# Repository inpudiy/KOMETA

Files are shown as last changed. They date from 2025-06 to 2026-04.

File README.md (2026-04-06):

# KOMETA

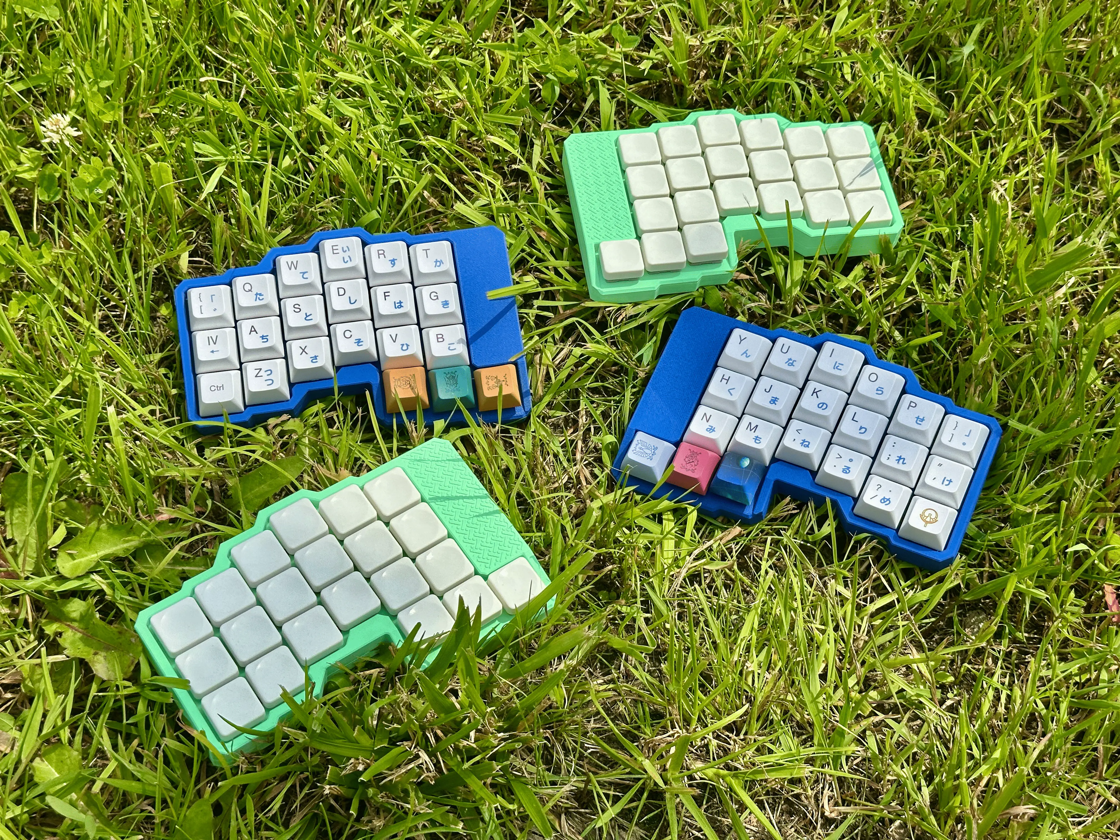
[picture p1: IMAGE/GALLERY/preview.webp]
All


KOMETA is a split keyboard built around Choc switches, designed for wireless operation with Pro Micro–sized microcontrollers. Its key feature is a mid-mount, hot-swappablecontroller design. To enable this, the PCB includes a USB-C port cutout, ensuring compatibility with popular wireless boards like: nice!nano or SuperMini

[Build Guide](BUILD.md) - [ZMK Firmware](https://github.com/inpudiy/zmk-KOMETA)

## Features

- Pro Micro-format microcontroller, compatible with mid-mount hot-swap installation
- Optimized for wireless: hardware power switch, reset button, battery solder pads, no LEDs, and ZMK firmware
- Choc V1/V2 switches with MX spacing (19 × 19 mm)
- 42-key layout with column stagger, inspired by the Jian keyboard
- 3D-printed case

## PCB Image

Bottom
Top

## Case

The repository includes two case variants: the original with angular walls, and a rounded community fork by @max_shu.

## BOM (Bill of Materials)

| Component | Qty |
| --- | --- |
| Pro Micro board: Super Mini nRF52840 / nice!nano | 2 |
| MSK12C02 Slide Switch | 2 |
| 301230 battery | 2 |
| TS342A2P | 2 |
| Silicone bumpers (6x2 mm) | 8 |
| Machine Pin Header Female | 48  |
| 50mm Industrial H62 brass wire 0.5mm thickness | 1 |
| PG1350 hot-swap socket | 42  |
| Diode 1N4148WS (SOD-323) | 42  |
| CHOC V1/2 switches | 42  |
| M2 Hexagon Nut | 12  |
| M2 Thin Flat Head Screw 9mm | 12  |

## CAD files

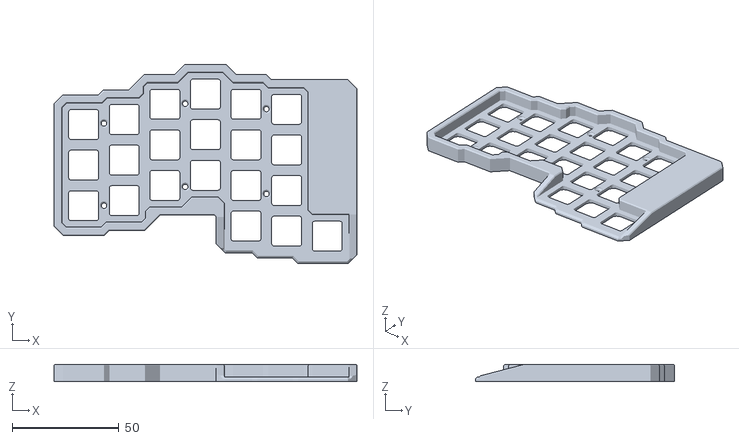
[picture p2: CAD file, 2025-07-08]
CASE/STL/RightPlateNoPattern.stl
141.8 x 93.2 x 8.05

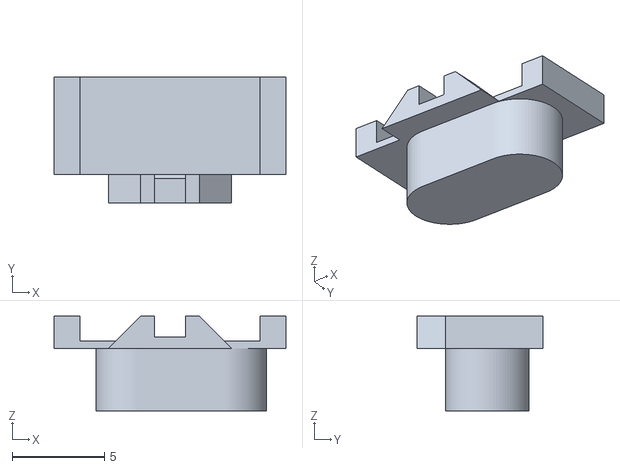
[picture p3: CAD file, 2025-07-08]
CASE/STL/LeftSlider.stl
12.6 x 6.83 x 5.15

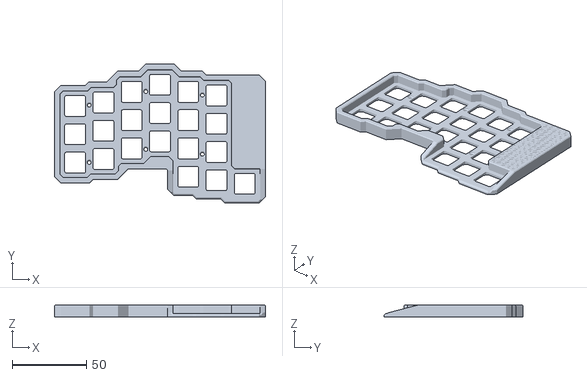
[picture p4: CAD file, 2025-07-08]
CASE/STL/LeftPlate.stl
141.8 x 93.2 x 8.05

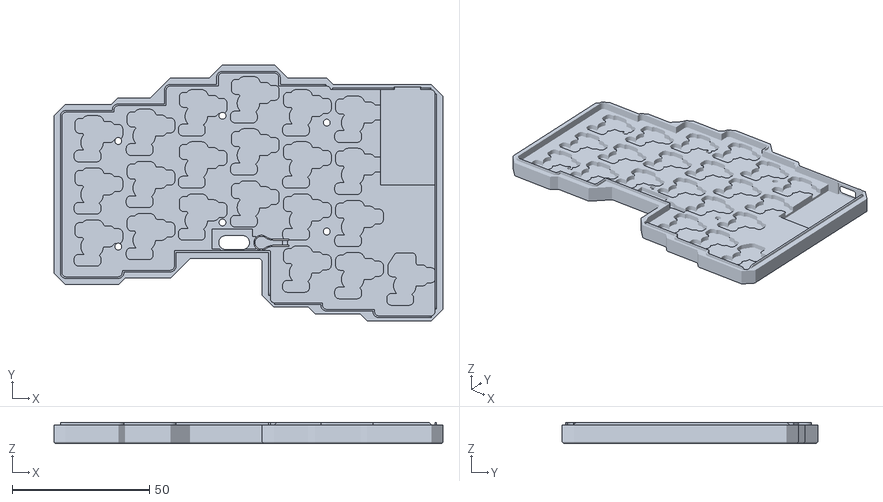
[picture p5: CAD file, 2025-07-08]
CASE/STL/LeftBottom.stl
141.8 x 93.2 x 7.70

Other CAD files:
CASE/STL/RightPlate.stl
CASE/STL/RightSlider.stl
CASE/STL/LeftPlateNoPattern.stl
CASE/STL/RightBottom.stl

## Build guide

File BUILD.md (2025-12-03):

## 1. Tool preparation

For soldering the KOMETA you will need: a soldering iron, solder, flux, side cutters, and tweezers.

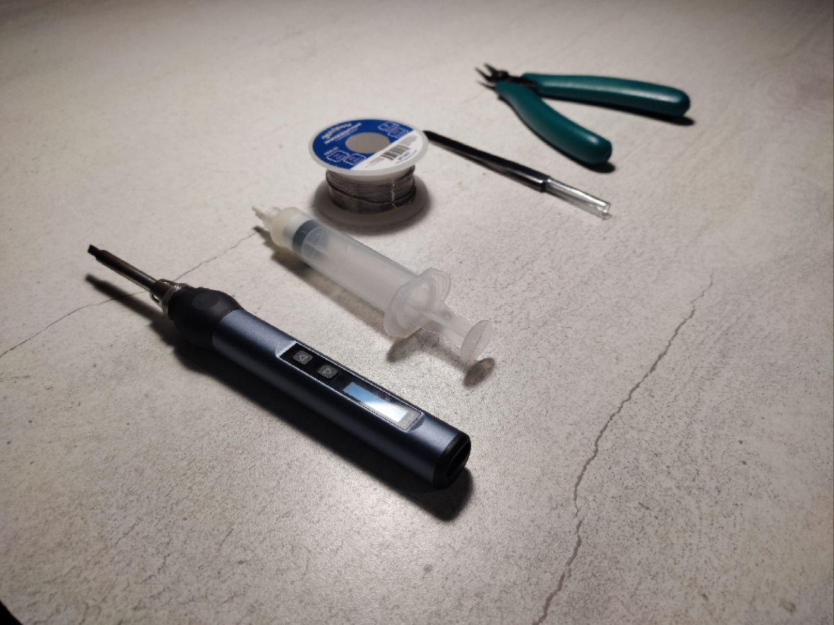
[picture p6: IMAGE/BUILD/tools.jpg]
tools


## 2. Component preparation

For soldering you will need: 2 PCBs, 42 PG1350 hot-swap sockets, 42 1N4148WS diodes, 2 TS342A2P and MSK12C02 switches, any Pro Micro–compatible development board based on the nRF52840 (for example, nice!nano or Super Mini nRF52840), as well as a 301230-sized lithium battery.

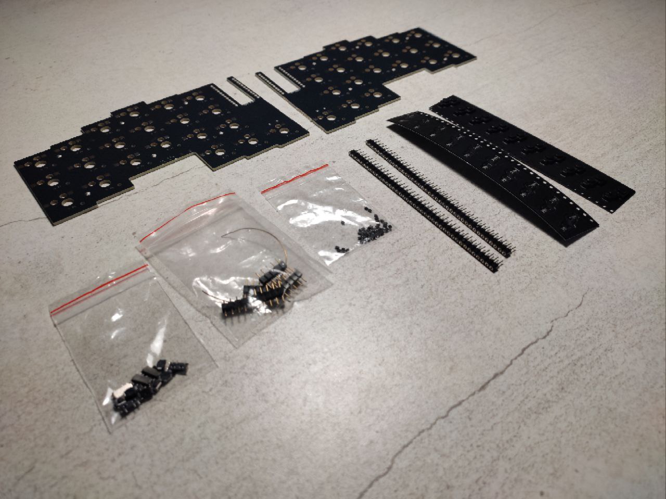
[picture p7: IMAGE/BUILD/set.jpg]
set


## 3. Soldering the diodes

The first step is to tin one pad of each diode footprint with a small amount of solder.

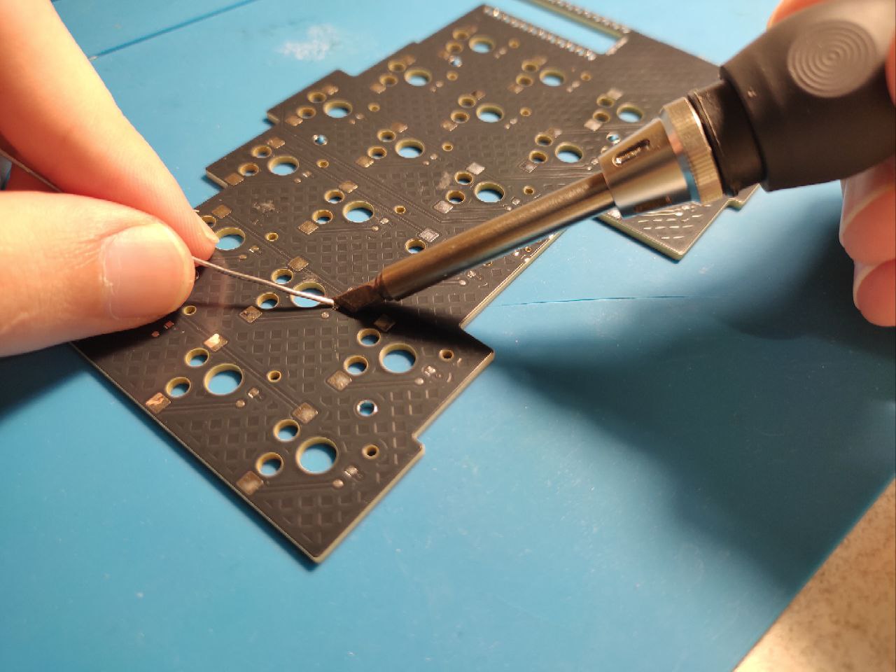
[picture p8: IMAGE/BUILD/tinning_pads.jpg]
tinnig


Next, align the stripe on the diode with the stripe on the PCB, which is located closer to the square pad.

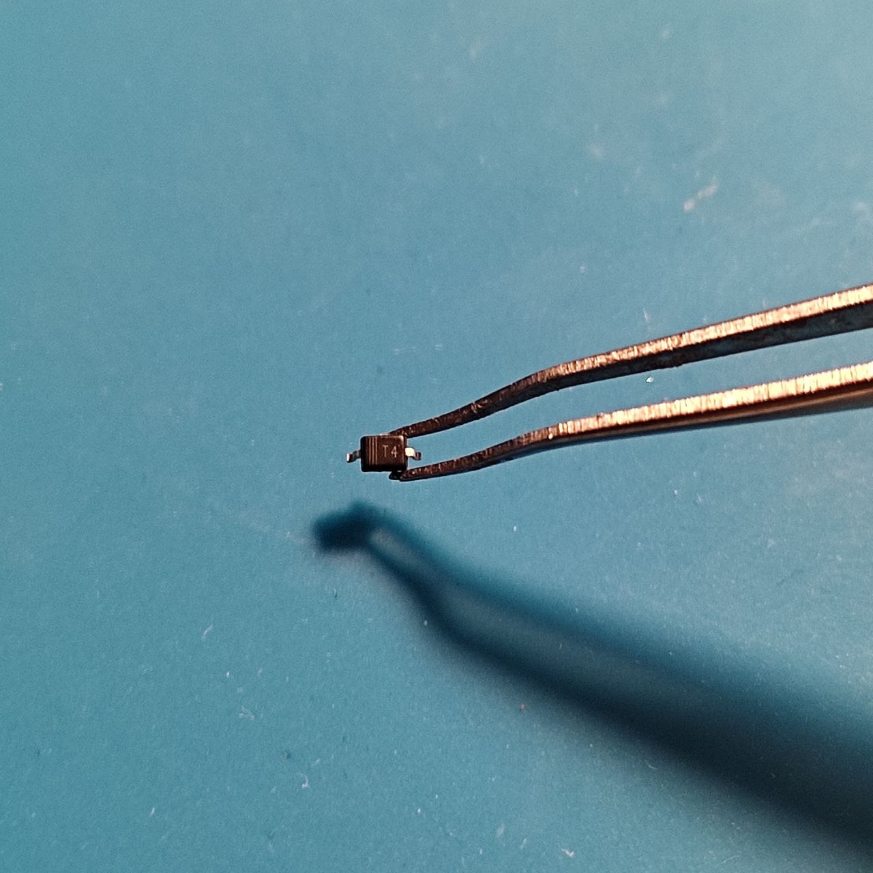
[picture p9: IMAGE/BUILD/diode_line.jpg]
diode_line

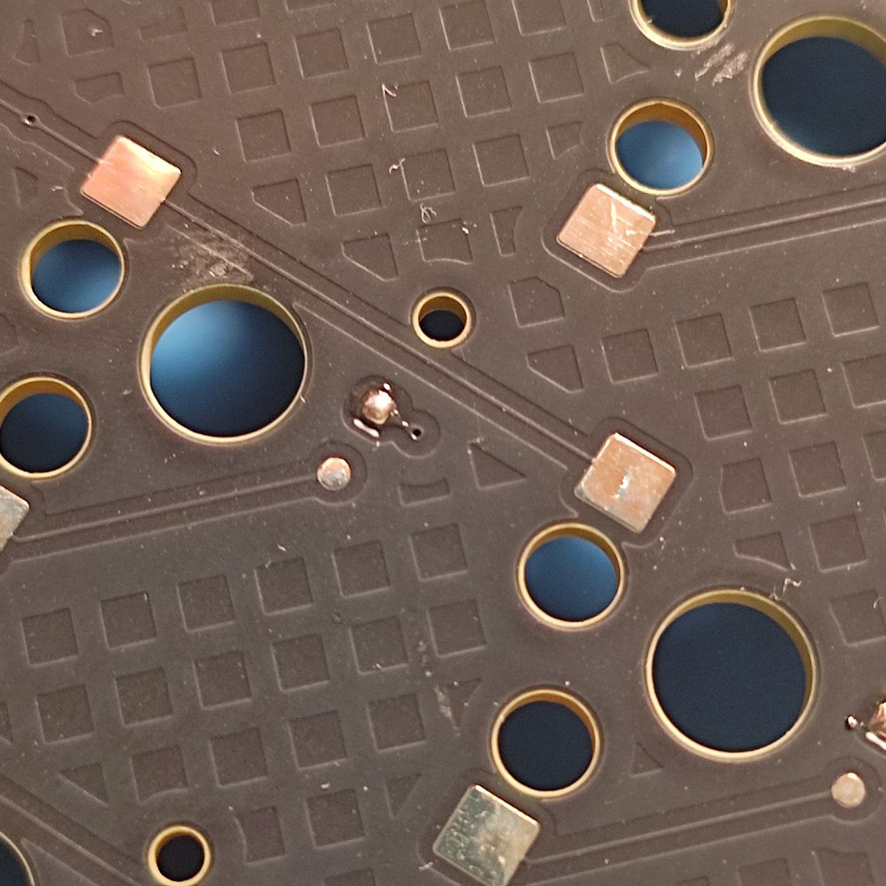
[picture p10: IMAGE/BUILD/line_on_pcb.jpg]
pcb_line


After that, use the soldering iron to reheat the tinned pad and place the diode in position.

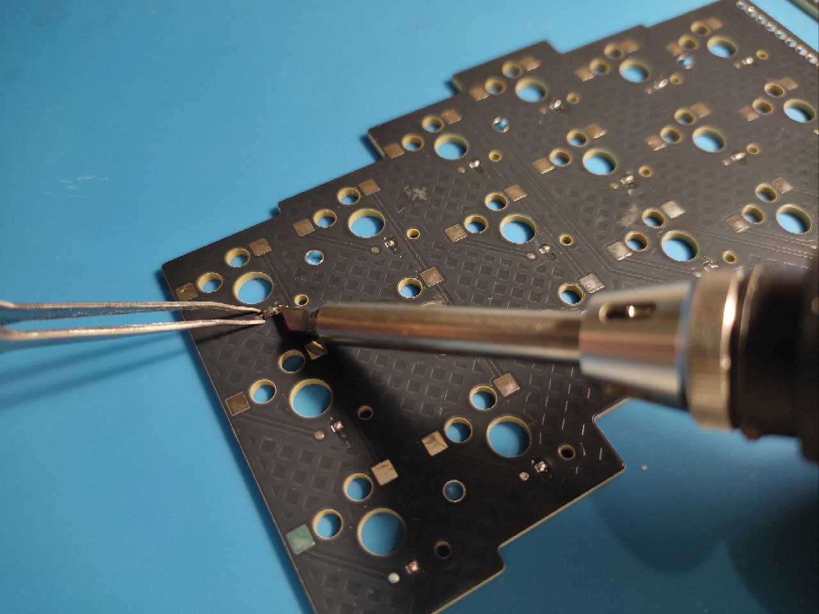
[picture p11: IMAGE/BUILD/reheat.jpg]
rehat


Once all the diodes are soldered on one side, solder the second contact of each diode.

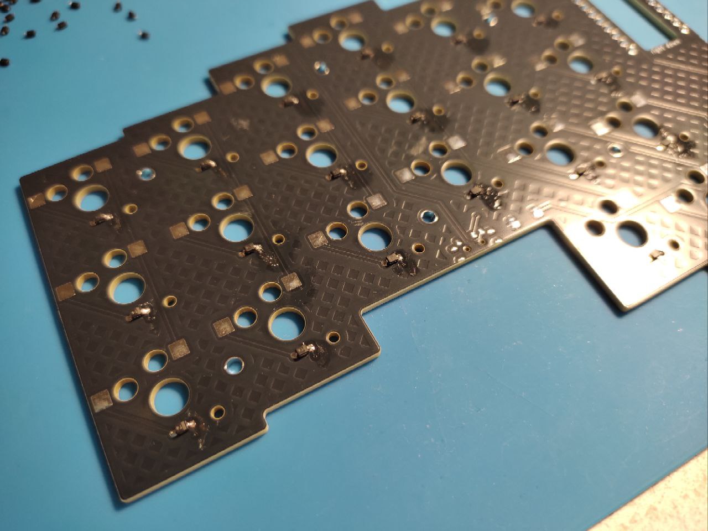
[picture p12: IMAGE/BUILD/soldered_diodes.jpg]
diode


## 4. Soldering the key sockets

Simply place all the hot-swap sockets into their footprints and apply solder on both sides.

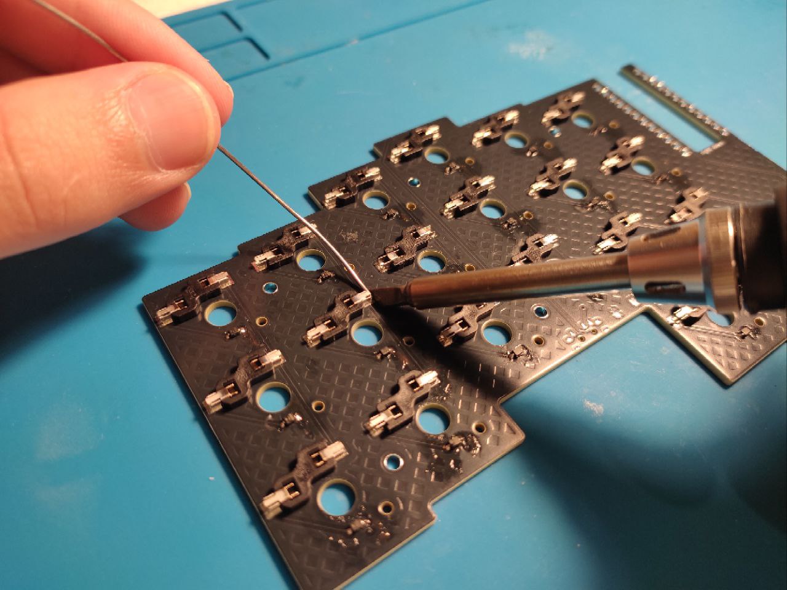
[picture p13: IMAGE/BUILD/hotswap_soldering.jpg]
hotswap


## 5. Soldering the Reset Button and Switch

Place the buttons into their footprints and apply flux with solder to the contacts.

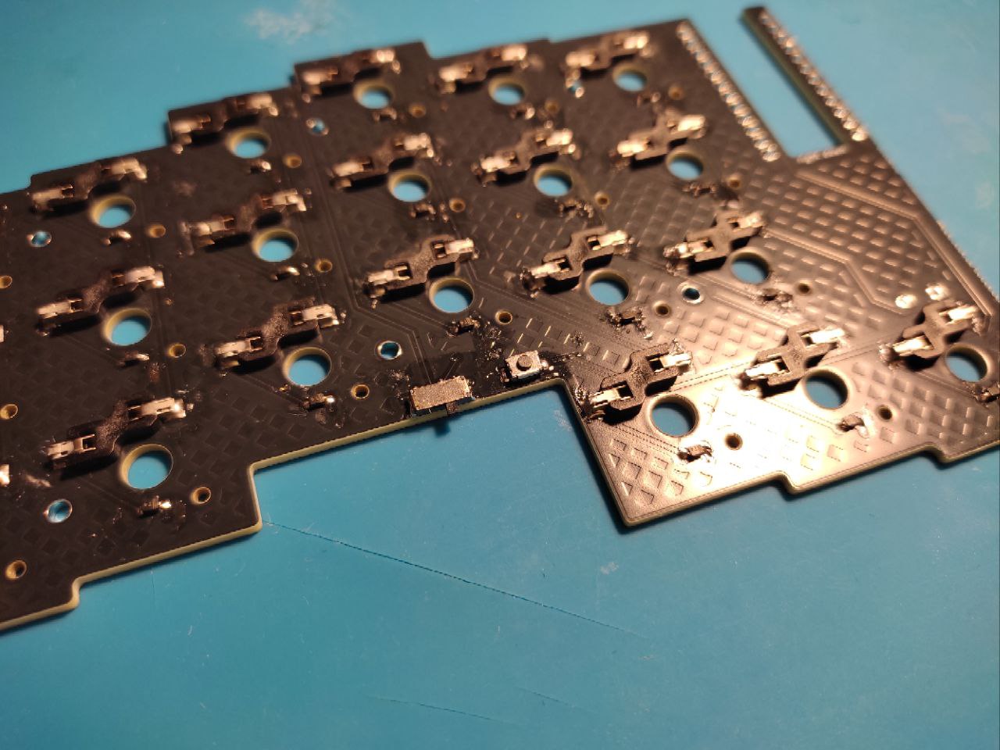
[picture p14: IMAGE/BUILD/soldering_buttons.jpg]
buttons


## 6. Installing the controller sockets

First, take rows of machine pin sockets and, using side cutters, extract 48 sockets. Simply snip the side and remove the excess plastic.

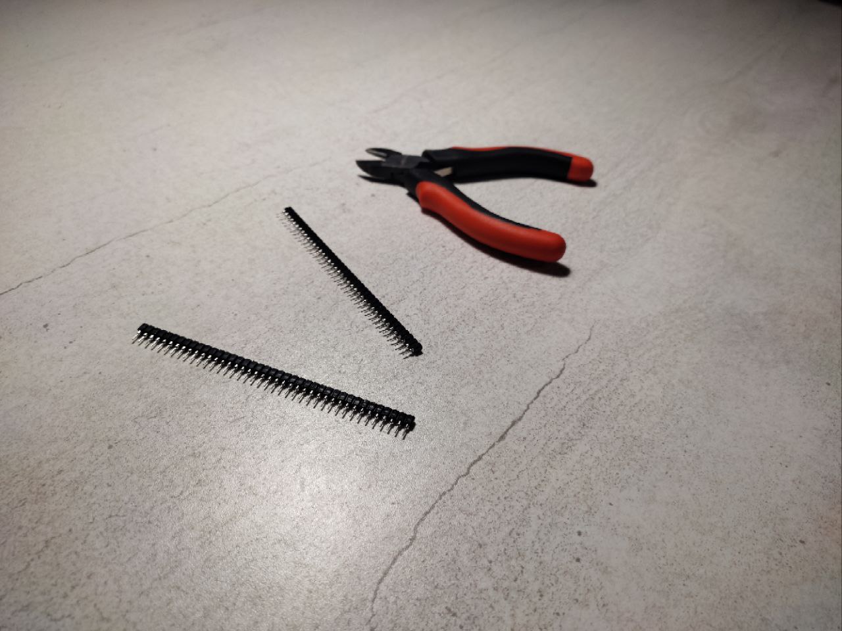
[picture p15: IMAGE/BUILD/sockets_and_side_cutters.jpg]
sockets_and_side_cutters

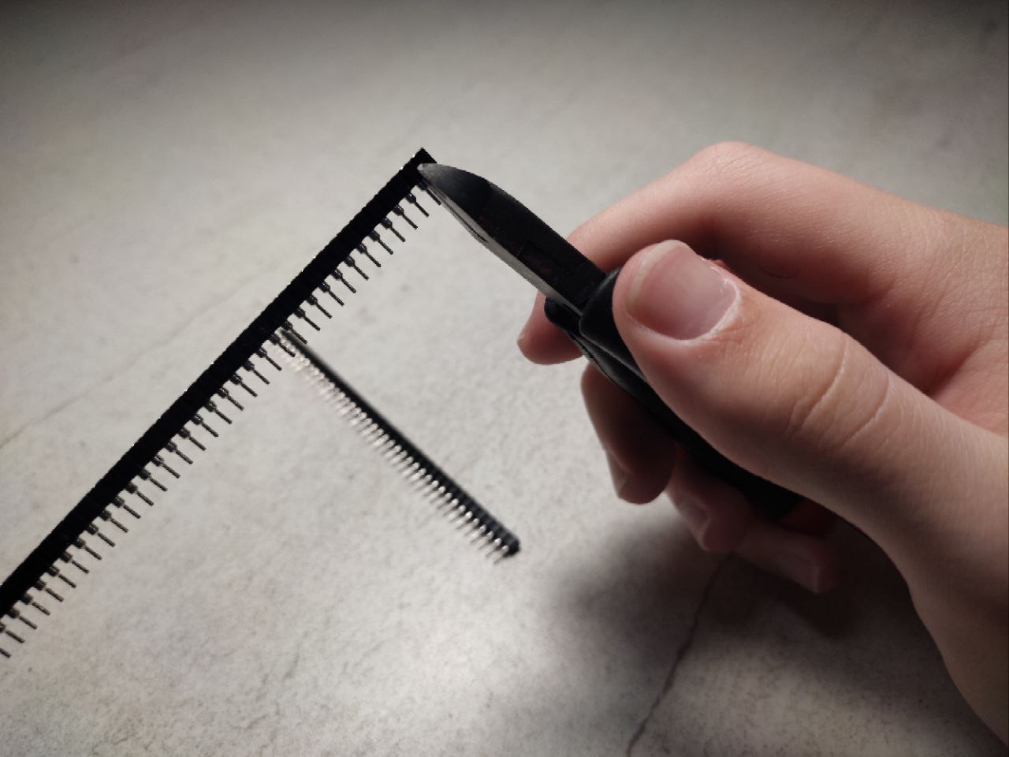
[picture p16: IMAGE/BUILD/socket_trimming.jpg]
socket_trimming

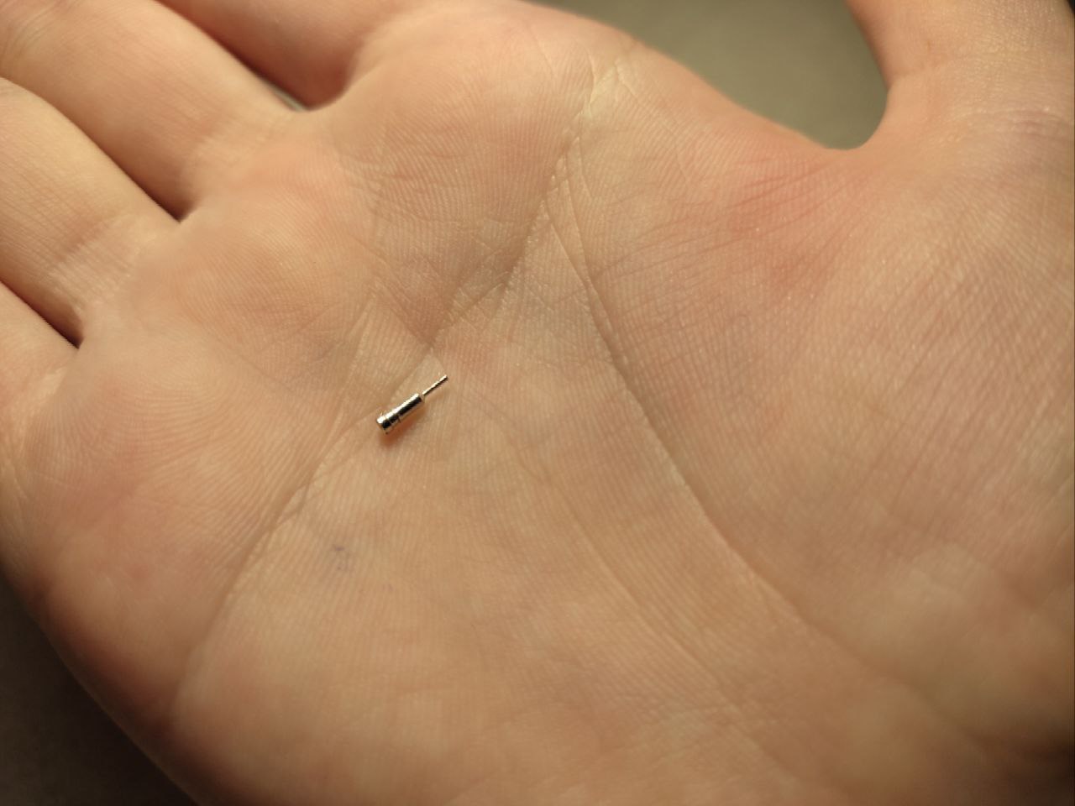
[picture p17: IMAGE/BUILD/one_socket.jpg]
one_socket

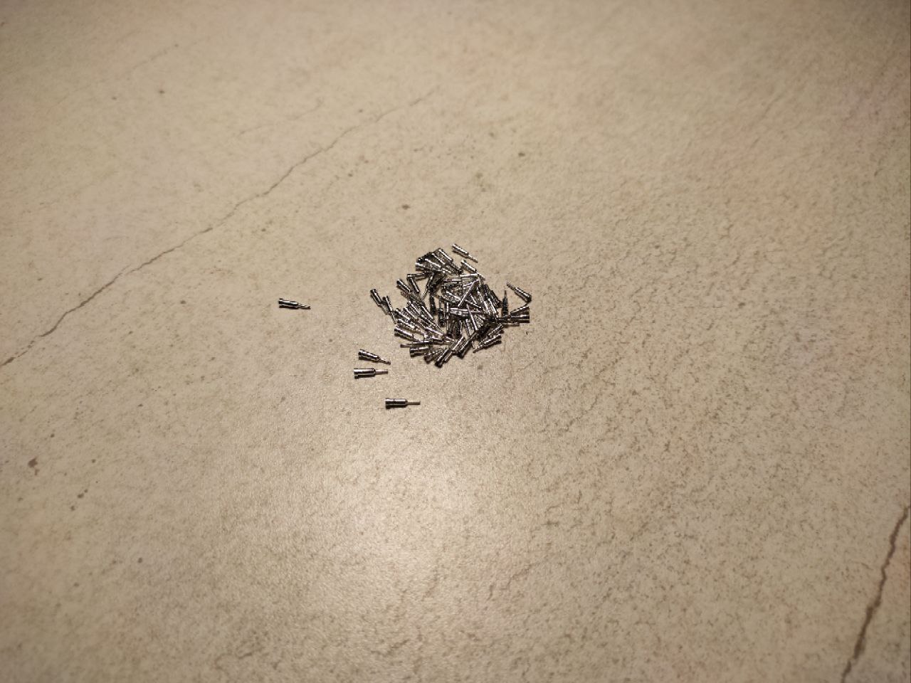
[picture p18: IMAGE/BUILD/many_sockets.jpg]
many_sockets


The second step is to place them, with the connector facing upward, on the bottom side of the PCB where all the components are located. You can use heat-resistant tape (DO NOT USE REGULAR TAPE, IT WILL DAMAGE THE PCB) to hold them in place during soldering.

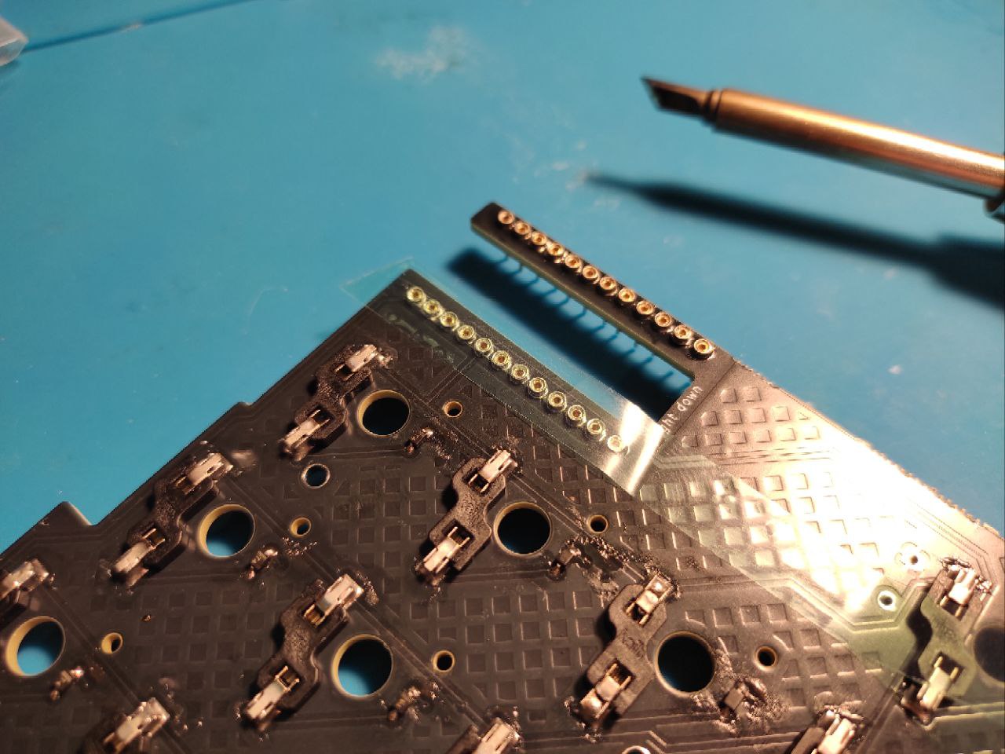
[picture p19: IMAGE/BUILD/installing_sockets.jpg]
installing_sockets


Flip the PCB to the top side and apply flux with solder.

Cut the ends of the pins with side cutters.

> [!WARNING]
> Be careful and use eye protection (PLEASE BE EXTRA CAREFUL, AS THE CUT PIECES CAN EASILY FLY INTO YOUR EYE OR YOUR MONITOR SCREEN).

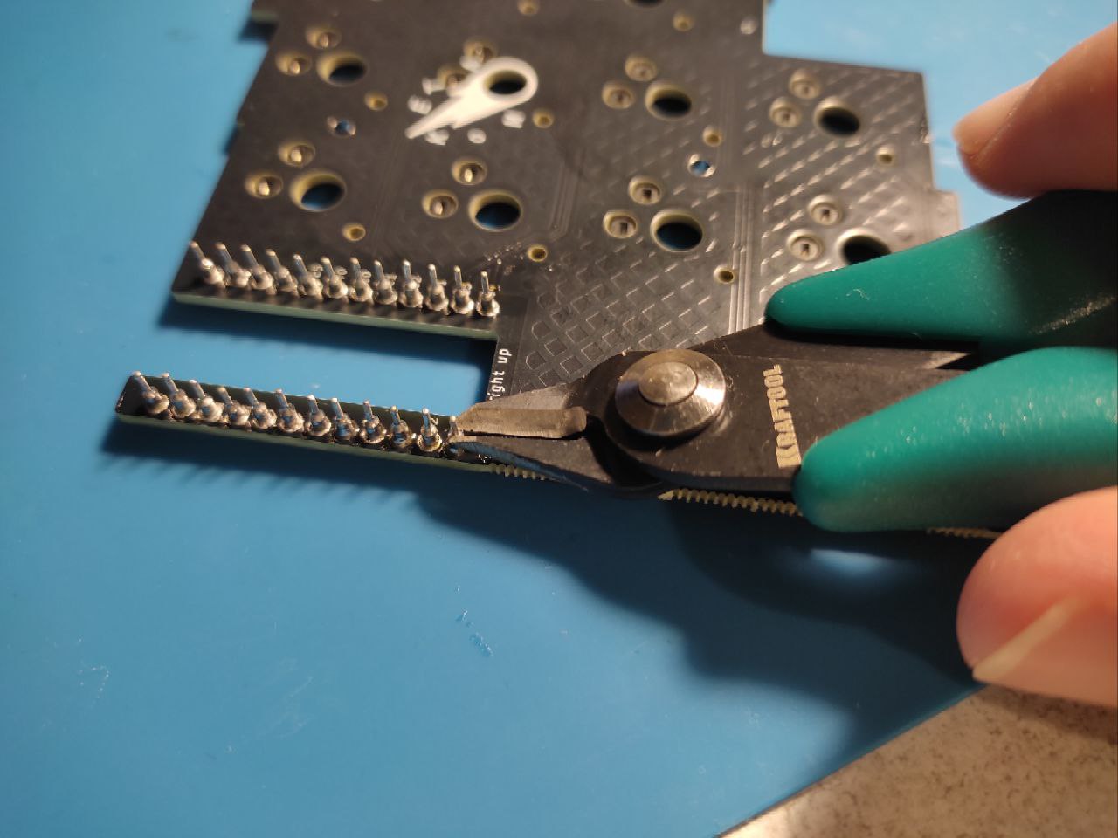
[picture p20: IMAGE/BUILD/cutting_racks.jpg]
cutting_racks


## 7. Soldering the controller

Place the controller on top of the sockets so that the top pins near the connector are not connected to the sockets.
Insert a wire into each contact and cut it with side cutters.

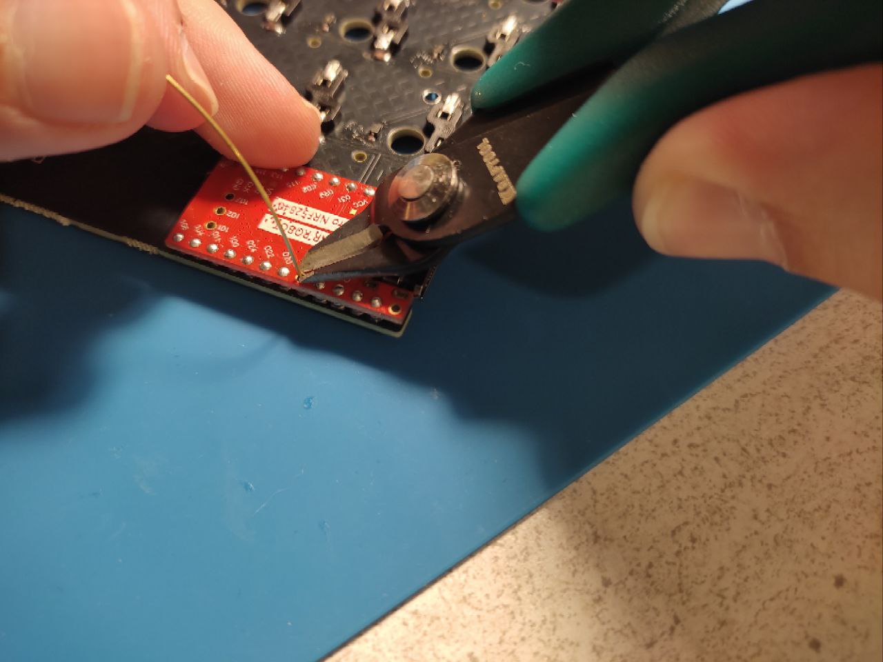
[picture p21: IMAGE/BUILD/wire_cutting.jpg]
wire_cutting


Once the wires are cut, apply flux and solder to all the contacts.

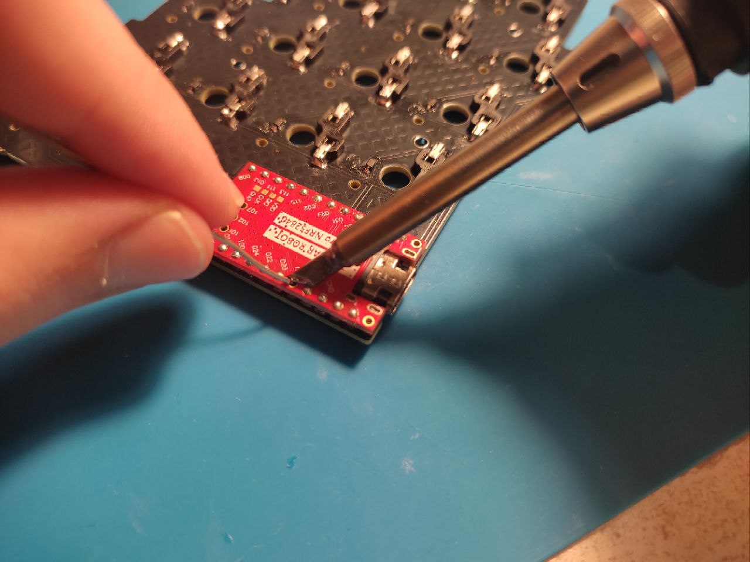
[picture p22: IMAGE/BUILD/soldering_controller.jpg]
soldering_controller


Be careful and make sure that the solder does not flow underneath the controller.

## 8. Installing the battery

Solder the red wire to the + and the black wire to the – on the top side of the PCB, and place the battery in the area near the controller.

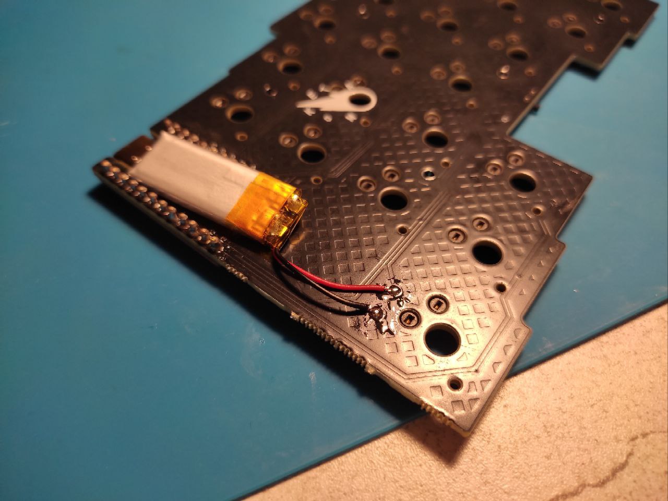
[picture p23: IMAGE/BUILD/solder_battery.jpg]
solder_battery


## 9. Flashing

After installing the controller on the board, connect the keyboard to your computer with a USB cable.

Download the archive named **firmware** from this repository: [https://github.com/inpudiy/kometa-zmk/releases](https://github.com/inpudiy/zmk-KOMETA/releases)

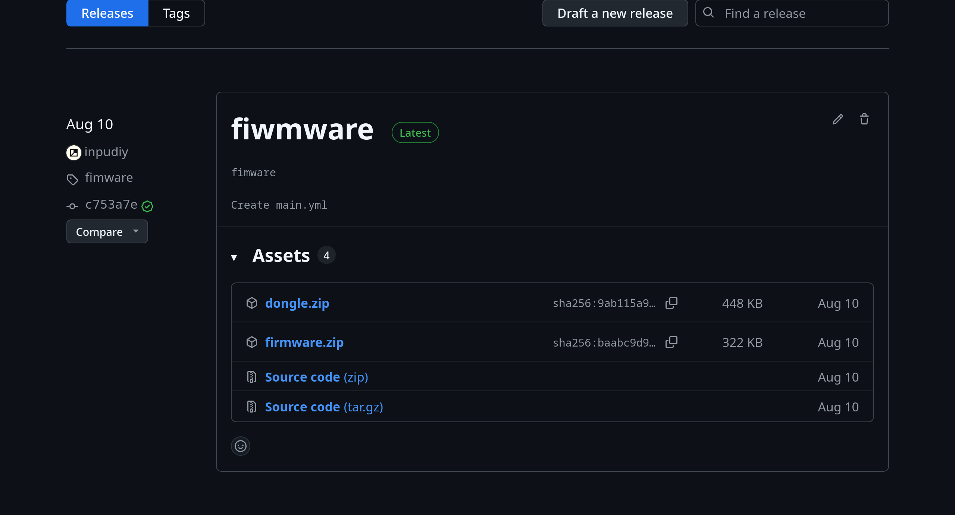
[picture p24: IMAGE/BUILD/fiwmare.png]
firmware


Unpack the archive — inside, you should find two files: one for the left half and one for the right half.

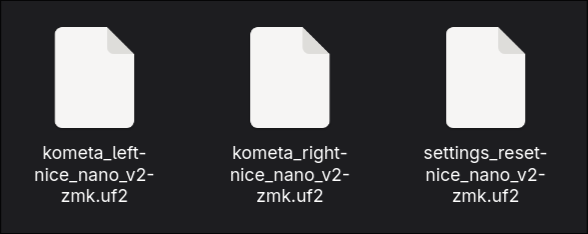
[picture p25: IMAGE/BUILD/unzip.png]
unzip


After extracting the files, press the button on the keyboard located next to the power switch. A new drive should appear in your file explorer.

button

If it doesn’t appear, make sure the controller is functioning (check if the LEDs blink when powered on) and that your cable supports data transfer.

Drag and drop the appropriate file onto the new drive for your half of the keyboard, then repeat the same process for the other half.

If you run into difficulties, please consult the official [troubleshooting](https://zmk.dev/docs/troubleshooting) guide.

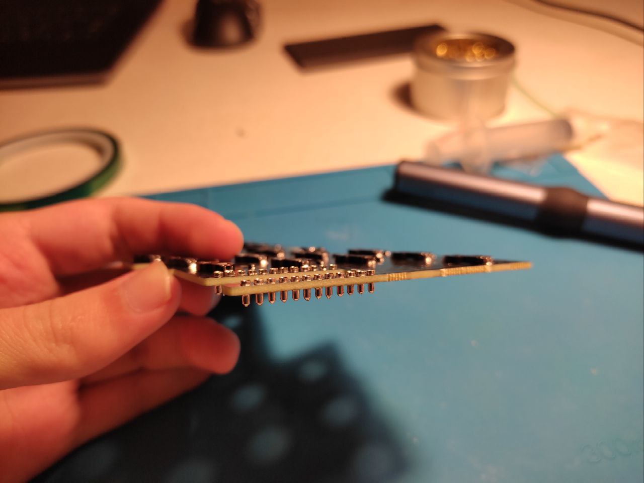
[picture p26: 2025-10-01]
IMAGE/BUILD/mid_mount_side.jpg

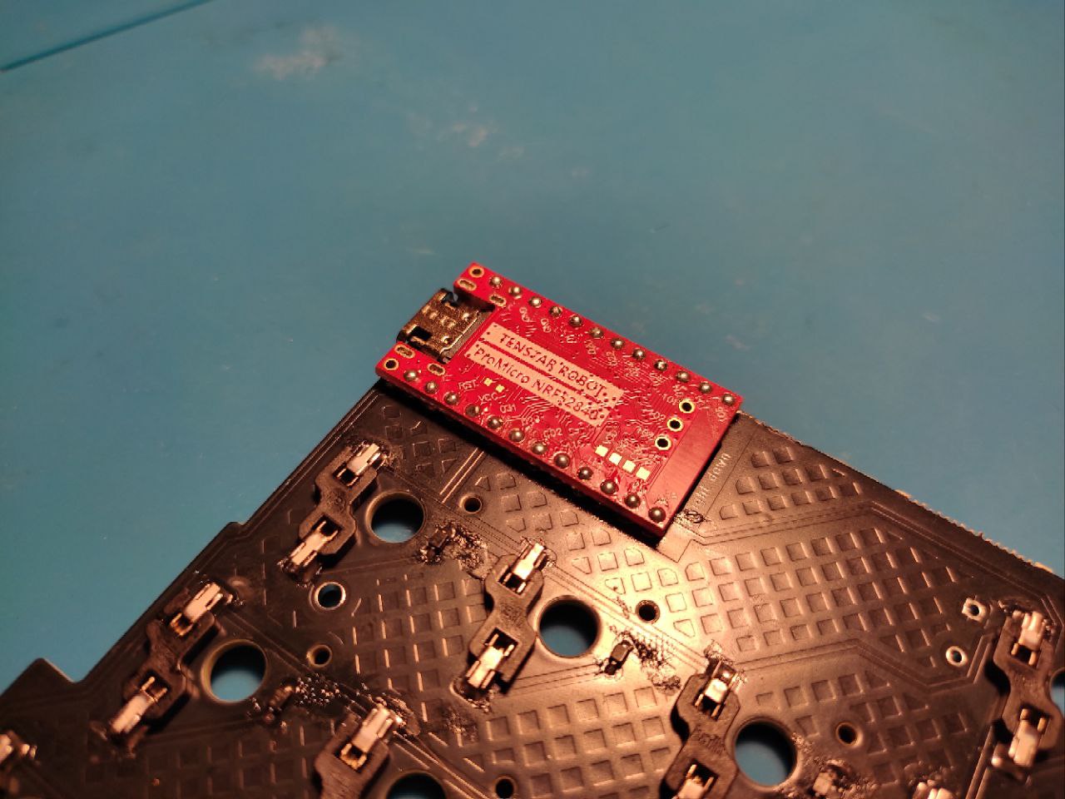
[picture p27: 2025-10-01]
IMAGE/BUILD/mid_mount_top.jpg

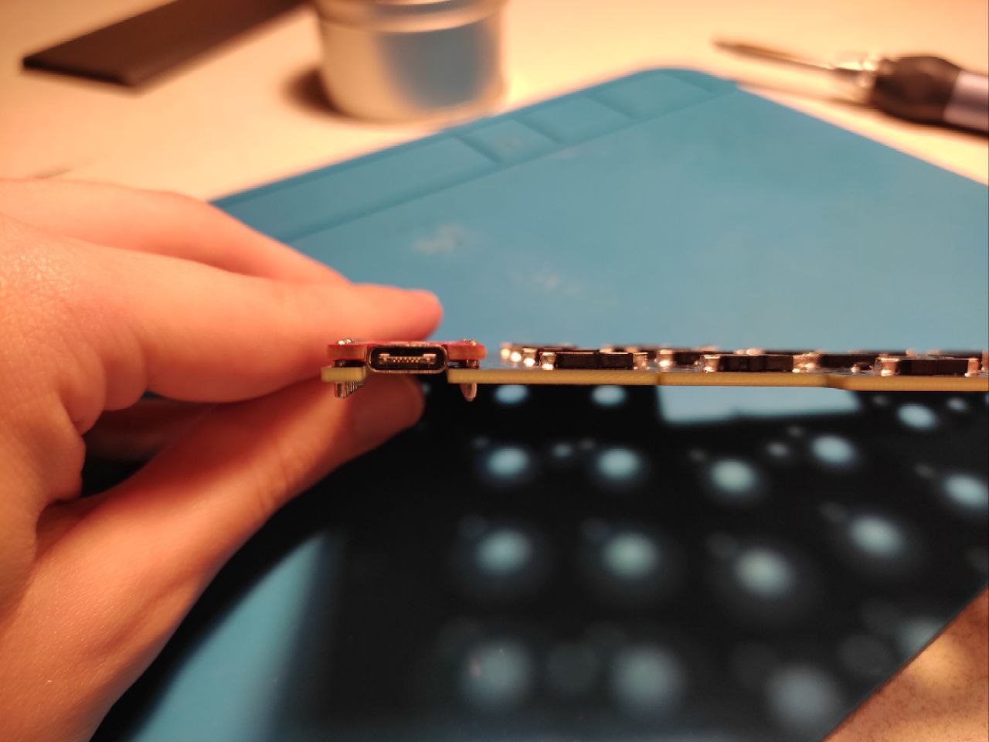
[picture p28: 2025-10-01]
IMAGE/BUILD/mid_mount_front.jpg

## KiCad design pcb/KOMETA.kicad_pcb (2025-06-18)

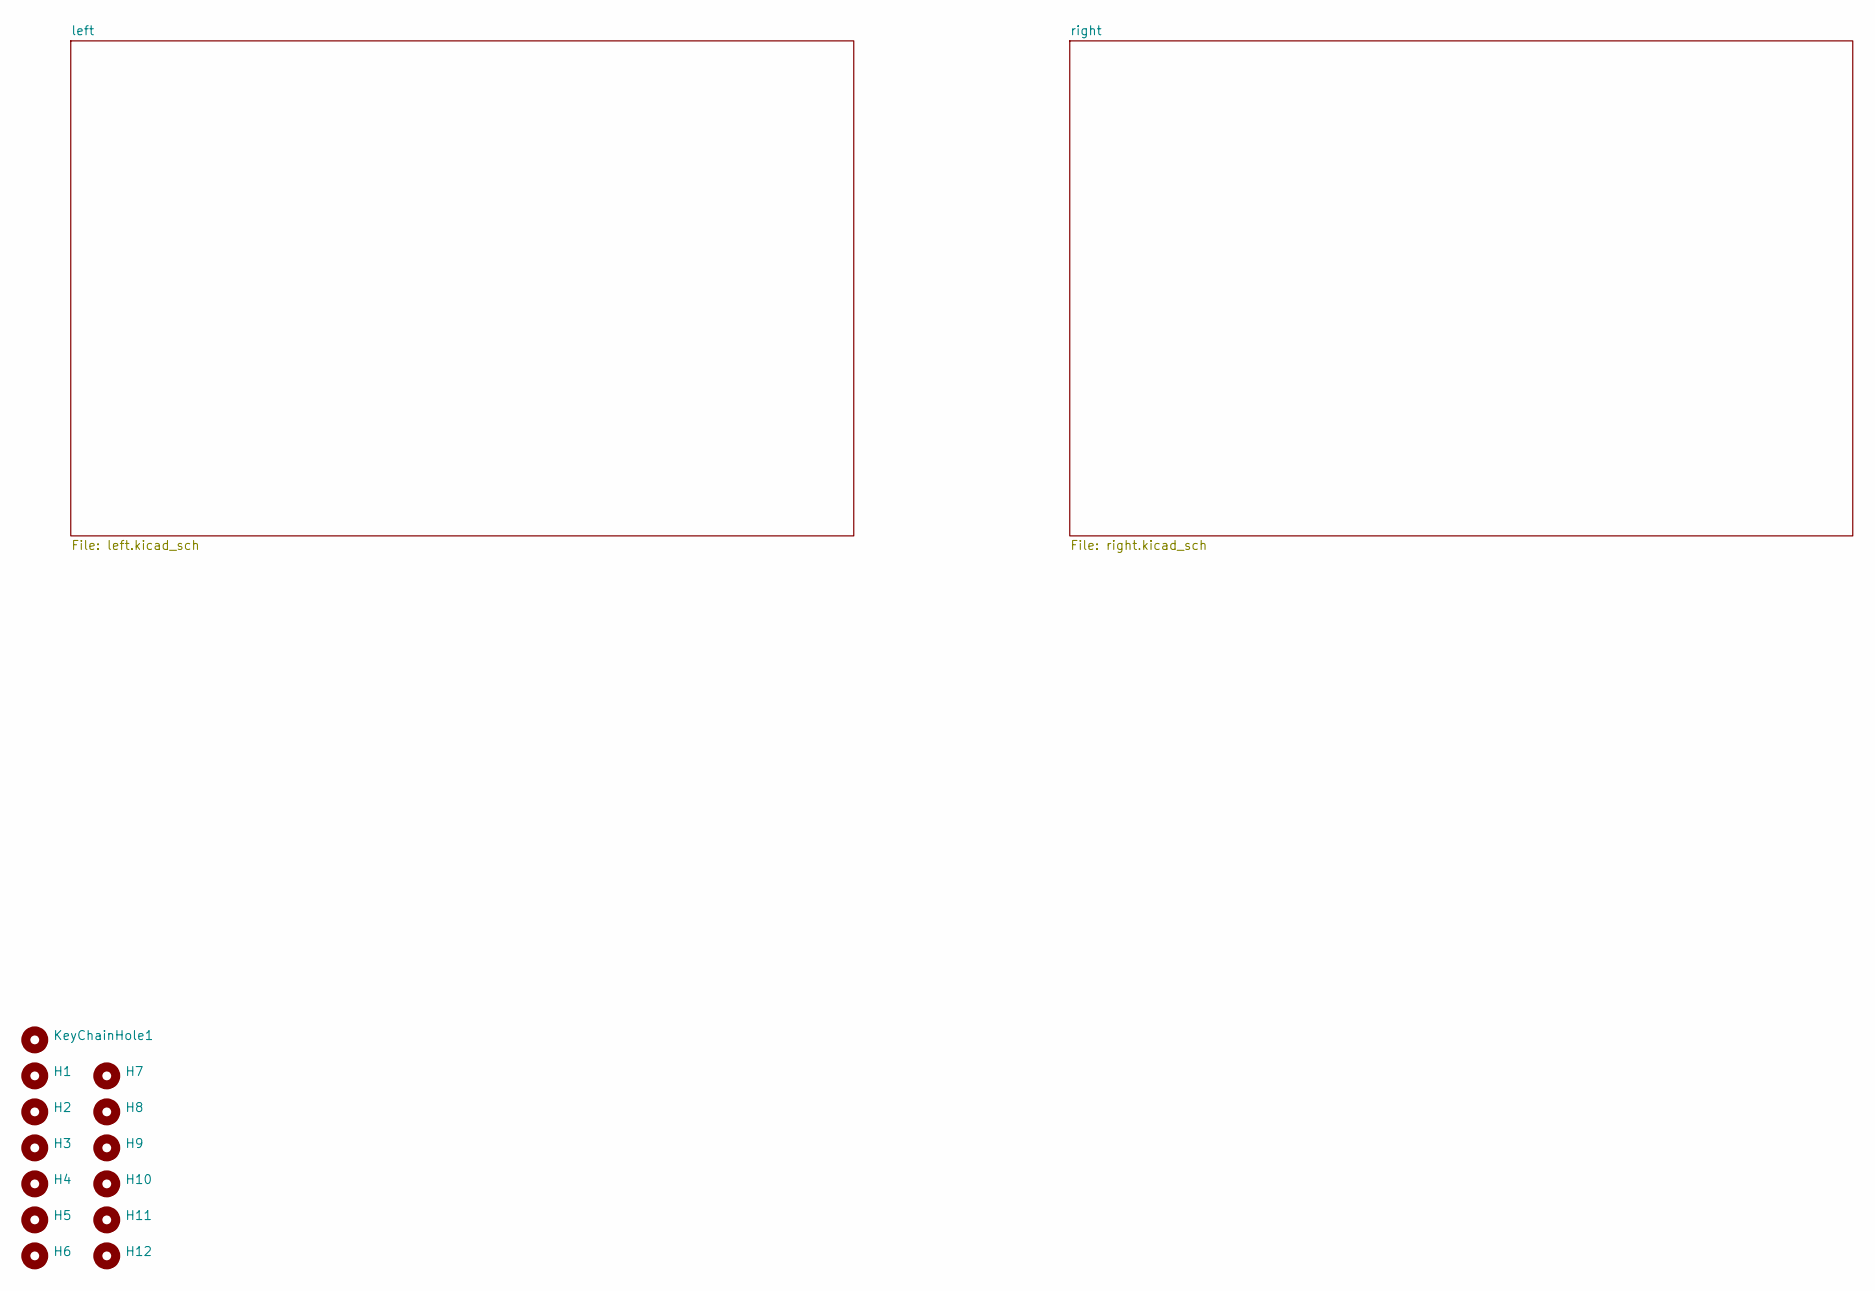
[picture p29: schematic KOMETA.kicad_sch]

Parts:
H1, H2, H3, H4, H5, H6, H7, H8, H9, H10, H11, H12: M2 Hole
KeyChainHole1: M5 hole

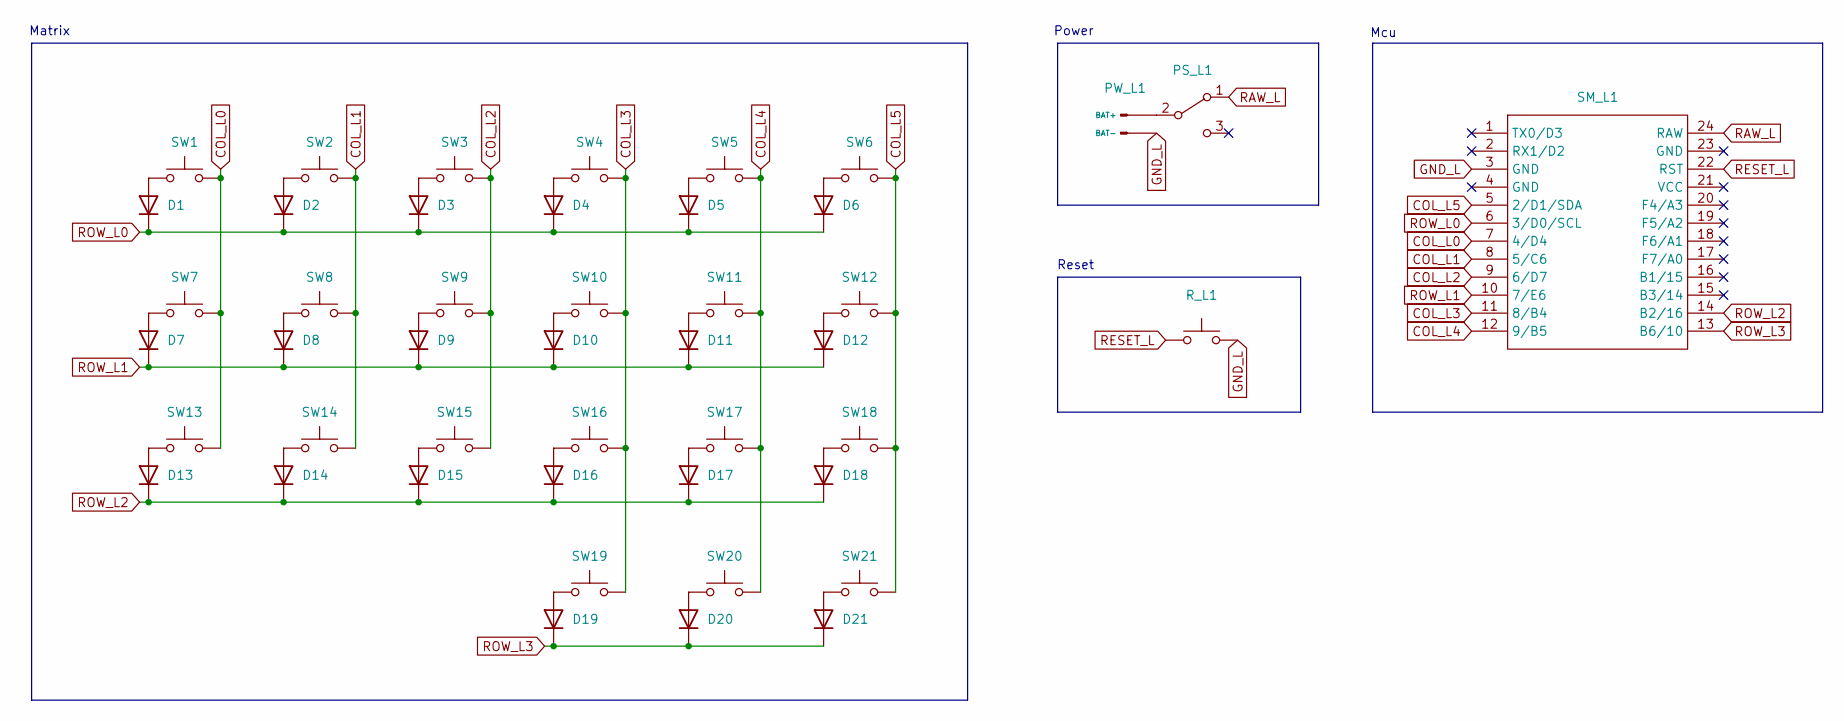
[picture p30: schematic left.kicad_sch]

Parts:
D1, D2, D3, D4, D5, D6, D7, D8, D9, D10, D11, D12, D13, D14, D15, D16, D17, D18, D19, D20, D21: Diode
PS_L1: MSK-12C02
PW_L1: Battery
R_L1: Reset
SM_L1: SuperMini
SW1, SW2, SW3, SW4, SW5, SW6, SW7, SW8, SW9, SW10, SW11, SW12, SW13, SW14, SW15, SW16, SW17, SW18, SW19, SW20, SW21: ChocV2

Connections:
COL_L0: SM_L1.7 (4/D4), SW1.2, SW7.2, SW13.2
COL_L1: SM_L1.8 (5/C6), SW2.2, SW8.2, SW14.2
COL_L2: SM_L1.9 (6/D7), SW3.2, SW9.2, SW15.2
COL_L3: SM_L1.11 (8/B4), SW4.2, SW10.2, SW16.2, SW19.2
COL_L4: SM_L1.12 (9/B5), SW5.2, SW11.2, SW17.2, SW20.2
COL_L5: SM_L1.5 (2/D1/SDA), SW6.2, SW12.2, SW18.2, SW21.2
GND_L: PW_L1.2 (BAT-), R_L1.2, SM_L1.3 (GND)
unnamed: D1.2 (A), SW1.1
unnamed: D2.2 (A), SW2.1
unnamed: D3.2 (A), SW3.1
unnamed: D4.2 (A), SW4.1
unnamed: D5.2 (A), SW5.1
unnamed: D6.2 (A), SW6.1
unnamed: D7.2 (A), SW7.1
unnamed: D8.2 (A), SW8.1
unnamed: D9.2 (A), SW9.1
unnamed: D10.2 (A), SW10.1
unnamed: D11.2 (A), SW11.1
unnamed: D12.2 (A), SW12.1
unnamed: D13.2 (A), SW13.1
unnamed: D14.2 (A), SW14.1
unnamed: D15.2 (A), SW15.1
unnamed: D16.2 (A), SW16.1
unnamed: D17.2 (A), SW17.1
unnamed: D18.2 (A), SW18.1
unnamed: D19.2 (A), SW19.1
unnamed: D20.2 (A), SW20.1
unnamed: D21.2 (A), SW21.1
unnamed: PS_L1.2 (B), PW_L1.1 (BAT+)
RAW_L: PS_L1.1 (A), SM_L1.24 (RAW)
RESET_L: R_L1.1, SM_L1.22 (RST)
ROW_L0: D1.1 (K), D2.1 (K), D3.1 (K), D4.1 (K), D5.1 (K), D6.1 (K), SM_L1.6 (3/D0/SCL)
ROW_L1: D7.1 (K), D8.1 (K), D9.1 (K), D10.1 (K), D11.1 (K), D12.1 (K), SM_L1.10 (7/E6)
ROW_L2: D13.1 (K), D14.1 (K), D15.1 (K), D16.1 (K), D17.1 (K), D18.1 (K), SM_L1.14 (B2/16)
ROW_L3: D19.1 (K), D20.1 (K), D21.1 (K), SM_L1.13 (B6/10)

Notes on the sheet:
Reset
Power
Matrix
Mcu

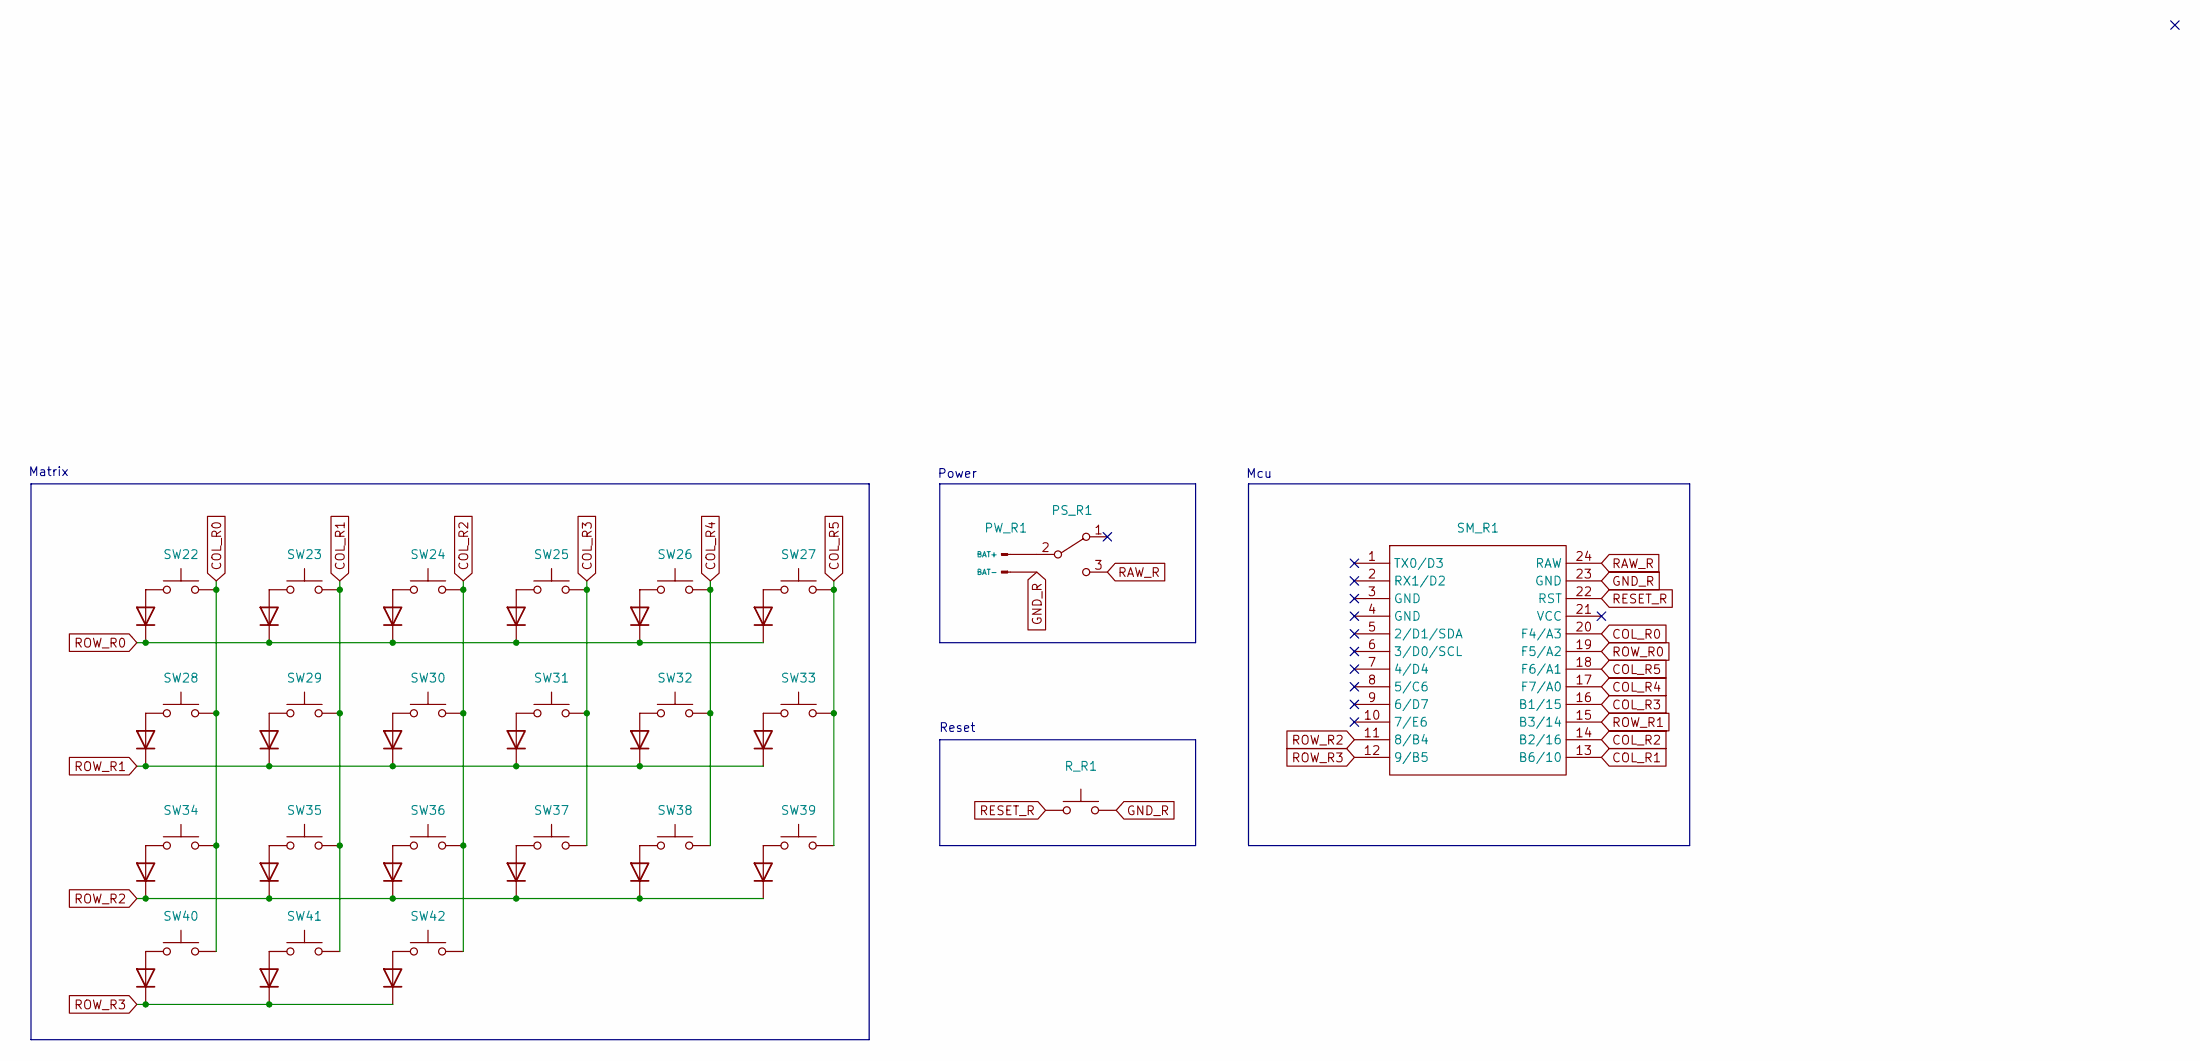
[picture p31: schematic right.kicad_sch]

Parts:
D22, D23, D24, D25, D26, D27, D28, D29, D30, D31, D32, D33, D34, D35, D36, D37, D38, D39, D40, D41, D42: Diode
PS_R1: MSK-12C02
PW_R1: Battery
R_R1: Reset
SM_R1: SuperMini
SW22, SW23, SW24, SW25, SW26, SW27, SW28, SW29, SW30, SW31, SW32, SW33, SW34, SW35, SW36, SW37, SW38, SW39, SW40, SW41, SW42: ChocV2

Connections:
COL_R0: SM_R1.20 (F4/A3), SW22.2, SW28.2, SW34.2, SW40.2
COL_R1: SM_R1.13 (B6/10), SW23.2, SW29.2, SW35.2, SW41.2
COL_R2: SM_R1.14 (B2/16), SW24.2, SW30.2, SW36.2, SW42.2
COL_R3: SM_R1.16 (B1/15), SW25.2, SW31.2, SW37.2
COL_R4: SM_R1.17 (F7/A0), SW26.2, SW32.2, SW38.2
COL_R5: SM_R1.18 (F6/A1), SW27.2, SW33.2, SW39.2
GND_R: PW_R1.2 (BAT-), R_R1.2, SM_R1.23 (GND)
unnamed: D22.2 (A), SW22.1
unnamed: D23.2 (A), SW23.1
unnamed: D24.2 (A), SW24.1
unnamed: D25.2 (A), SW25.1
unnamed: D26.2 (A), SW26.1
unnamed: D27.2 (A), SW27.1
unnamed: D28.2 (A), SW28.1
unnamed: D29.2 (A), SW29.1
unnamed: D30.2 (A), SW30.1
unnamed: D31.2 (A), SW31.1
unnamed: D32.2 (A), SW32.1
unnamed: D33.2 (A), SW33.1
unnamed: D34.2 (A), SW34.1
unnamed: D35.2 (A), SW35.1
unnamed: D36.2 (A), SW36.1
unnamed: D37.2 (A), SW37.1
unnamed: D38.2 (A), SW38.1
unnamed: D39.2 (A), SW39.1
unnamed: D40.2 (A), SW40.1
unnamed: D41.2 (A), SW41.1
unnamed: D42.2 (A), SW42.1
unnamed: PS_R1.2 (B), PW_R1.1 (BAT+)
RAW_R: PS_R1.3 (C), SM_R1.24 (RAW)
RESET_R: R_R1.1, SM_R1.22 (RST)
ROW_R0: D22.1 (K), D23.1 (K), D24.1 (K), D25.1 (K), D26.1 (K), D27.1 (K), SM_R1.19 (F5/A2)
ROW_R1: D28.1 (K), D29.1 (K), D30.1 (K), D31.1 (K), D32.1 (K), D33.1 (K), SM_R1.15 (B3/14)
ROW_R2: D34.1 (K), D35.1 (K), D36.1 (K), D37.1 (K), D38.1 (K), D39.1 (K), SM_R1.11 (8/B4)
ROW_R3: D40.1 (K), D41.1 (K), D42.1 (K), SM_R1.12 (9/B5)

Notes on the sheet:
Reset
Power
Mcu
Matrix

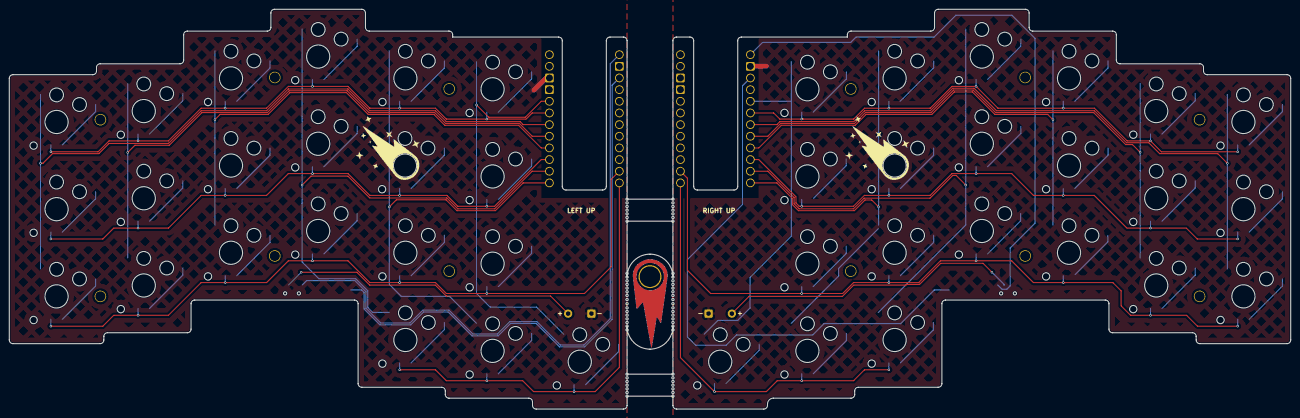
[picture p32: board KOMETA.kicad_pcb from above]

Board: 2 copper layers, 279.2 x 87.1 mm, 113 parts (0 on the bottom side), 70 nets.

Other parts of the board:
BH: Val**; BreakHole
BH#2, BH#3, BH#4, BH#5, BH#6, BH#7, BH#8: Val**; BreakHole

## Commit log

2025-05-22 upload source
    [KOMETA-B_Cu.gbr, KOMETA-B_Mask.gbr, KOMETA-B_Paste.gbr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]
2025-06-04 update silkscreen
    [KOMETA-B_Cu.gbr, KOMETA-B_Mask.gbr, KOMETA-B_Paste.gbr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]
2025-06-04 add pcb image
2025-06-05 update footrpint
    [KOMETA-B_Cu.gbr, KOMETA-B_Mask.gbr, KOMETA-B_Paste.gbr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]
2025-06-05 update footprint
    [KOMETA.kicad_pcb, KOMETA.kicad_sch, left.kicad_sch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]
2025-06-05 fix silkscreen
    [KOMETA-B_Cu.gbr, KOMETA-B_Mask.gbr, KOMETA-B_Paste.gbr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]
2025-06-18 fix EdgeCuts
    [KOMETA-B_Cu.gbr, KOMETA-B_Mask.gbr, KOMETA-B_Paste.gbr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]
2025-07-08 add case files & update readme
    [LeftBottom.stl, LeftPlate.stl, LeftPlateNoPattern.stl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]
2025-07-19 add support choc v1
    [KOMETA-B_Cu.gbr, KOMETA-B_Mask.gbr, KOMETA-B_Paste.gbr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]
2025-07-19 update BOM
2025-09-12 upload v1.1
    [KOMETA-B_Cu.gbr, KOMETA-B_Mask.gbr, KOMETA-B_Paste.gbr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]
2025-09-16 update pcb
    [KOMETA-B_Cu.gbr, KOMETA-B_Mask.gbr, KOMETA-B_Paste.gbr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]
2025-10-01 write solder guide
2025-12-03 rename directory
    [KOMETA-B_Cu.gbr, KOMETA-B_Mask.gbr, KOMETA-B_Paste.gbr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]
2025-12-03 update footpint
    [KOMETA-B_Cu.gbr, KOMETA-B_Mask.gbr, KOMETA-B_Paste.gbr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]
2026-01-11 add led sh and pretty
    [left.kicad_sch, right.kicad_sch]
2026-01-20 Added rgb led, made reset and powerswitch twoside solderable
2026-02-05 Experimental KS27/KS33 support
    [left.kicad_sch, right.kicad_sch]
2026-03-20 Remove ks27/ks33 support, fix mcu board cutout
    [left.kicad_sch, right.kicad_sch]
2026-04-06 upload case fork
